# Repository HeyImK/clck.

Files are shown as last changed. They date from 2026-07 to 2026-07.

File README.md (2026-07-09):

# clck.

A custom battery-powered alarm clock built for the [Hack Club BLARE](https://blare.hackclub.com/) program.

The goal of this project was simple: build an aesthetic alarm clock with a hint of brutalism style that doesn't use cheap rubber buttons. Instead, it uses four Cherry MX mechanical keyboard switches, a custom PCB, and a 3D printed enclosure. Everything is powered by a Wemos ESP32-C3 Mini, which handles the display, buttons,buzzer, etc. Btw Sponsored by Hack Club too!!!

## Overview

### Enclosure

| Front | Back |
|---|---|
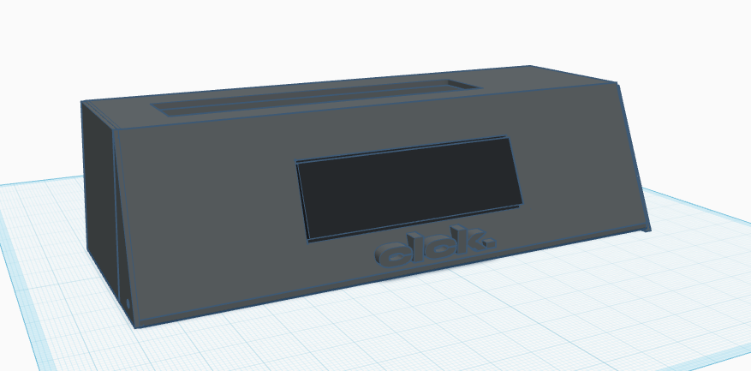
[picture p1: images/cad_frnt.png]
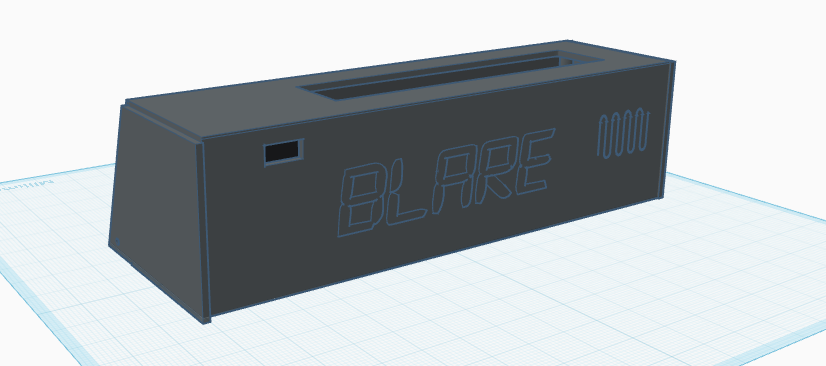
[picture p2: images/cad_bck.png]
|  |  |

### PCB

| Front | Back |
|---|---|
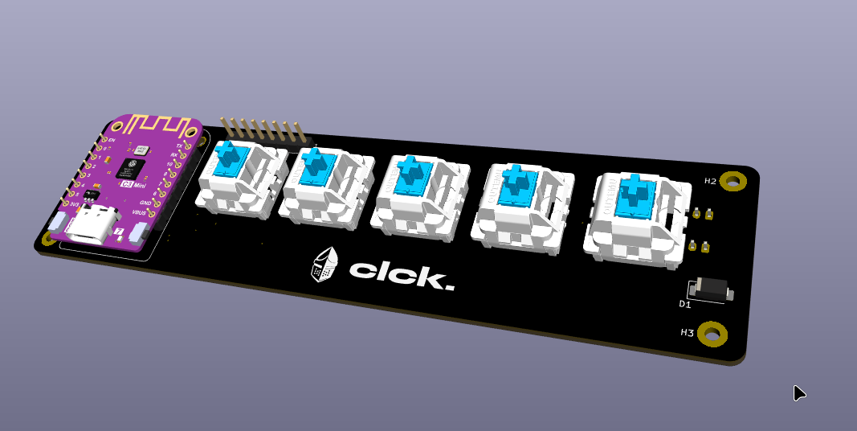
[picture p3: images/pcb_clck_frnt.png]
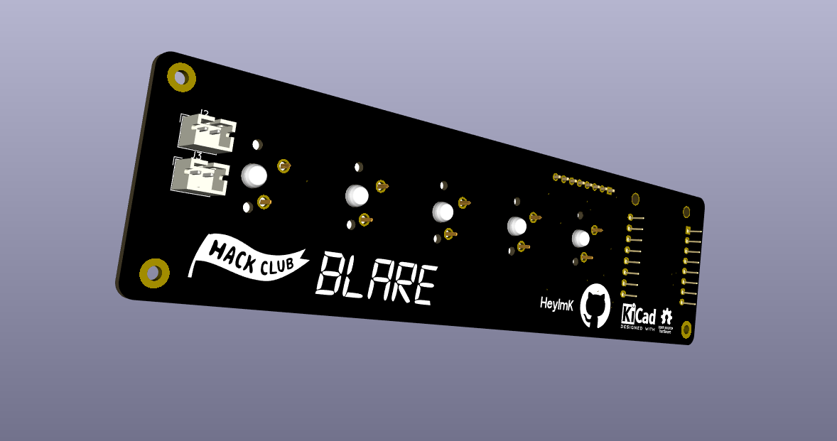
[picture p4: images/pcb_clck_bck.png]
|  |  |

### Electronics

| Schematic | PCB Routing |
|---|---|
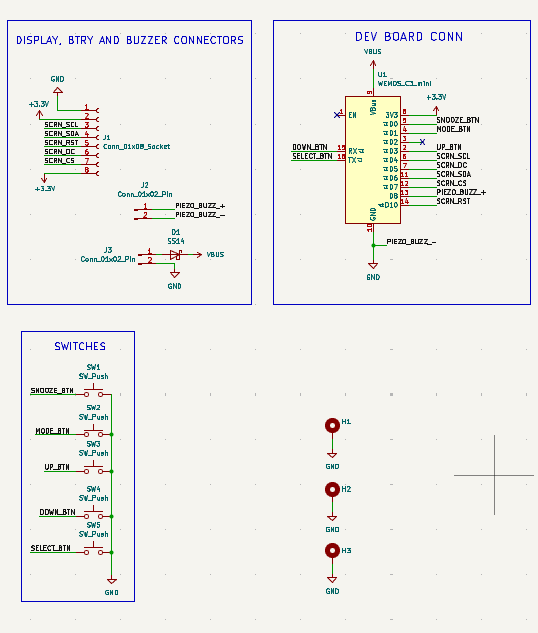
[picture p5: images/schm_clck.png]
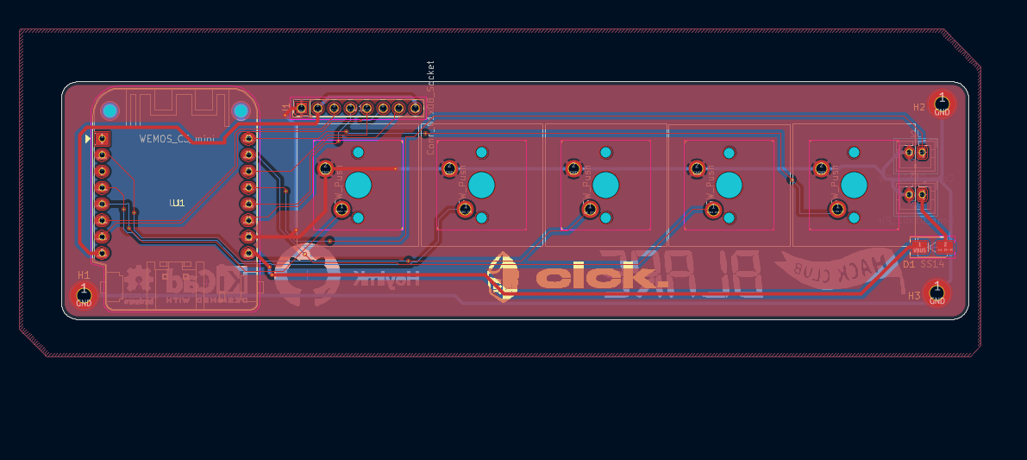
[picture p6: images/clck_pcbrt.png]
|  |  |

## Hardware

- Wemos ESP32-C3 Mini dev-board
- 2.25" SPI TFT display
- 4 Cherry MX mechanical switches
- Piezo buzzer
- Schottky diode (SS14)

The battery connects through a JST 2.0 connector and is charged using a external TP4056 module. 

## Pin Mapping

The ESP32-C3 Mini doesn't have many GPIOs, so every pin has been used by the display,buttons,buzzer etc.  

| Component | ESP32-C3 Pin(s) | Notes |
|---|---|---|
| Display (SPI) | GPIO4, GPIO6, GPIO7, GPIO2, GPIO10 | SCK, MOSI, CS, DC, RST |
| Piezo buzzer | GPIO8 | Connected to the positive terminal |
| Buttons | GPIO0, GPIO1, GPIO20, GPIO21 | Main control buttons |
| Battery input | VBUS |Connect to a charging module first |

## Assembly

The switch plate is designed around a thickness of **1.5 mm**. Making it thicker will prevent the Cherry MX switches from snapping into place correctly.

Before connecting the battery check the battery polarity.

## License

CERN-OHL-S-2.0 license

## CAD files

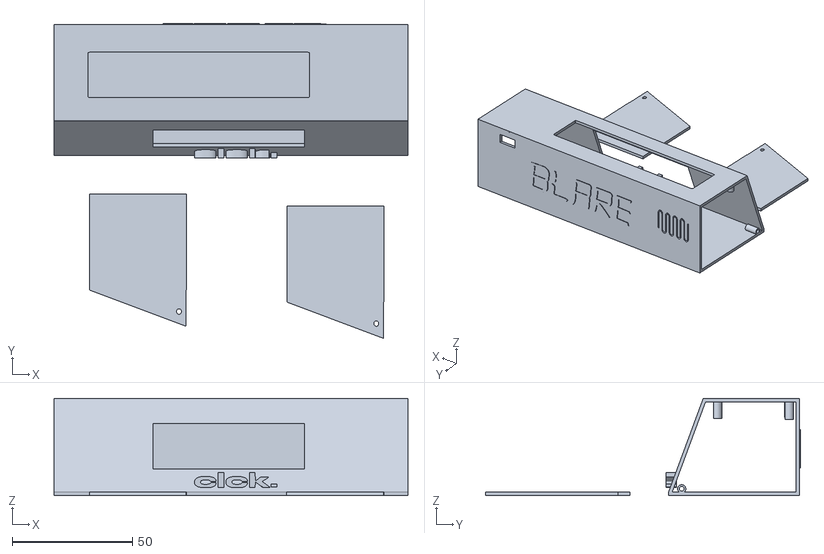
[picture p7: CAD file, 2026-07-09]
cad/clck. case.stl
147.1 x 130.8 x 40.5

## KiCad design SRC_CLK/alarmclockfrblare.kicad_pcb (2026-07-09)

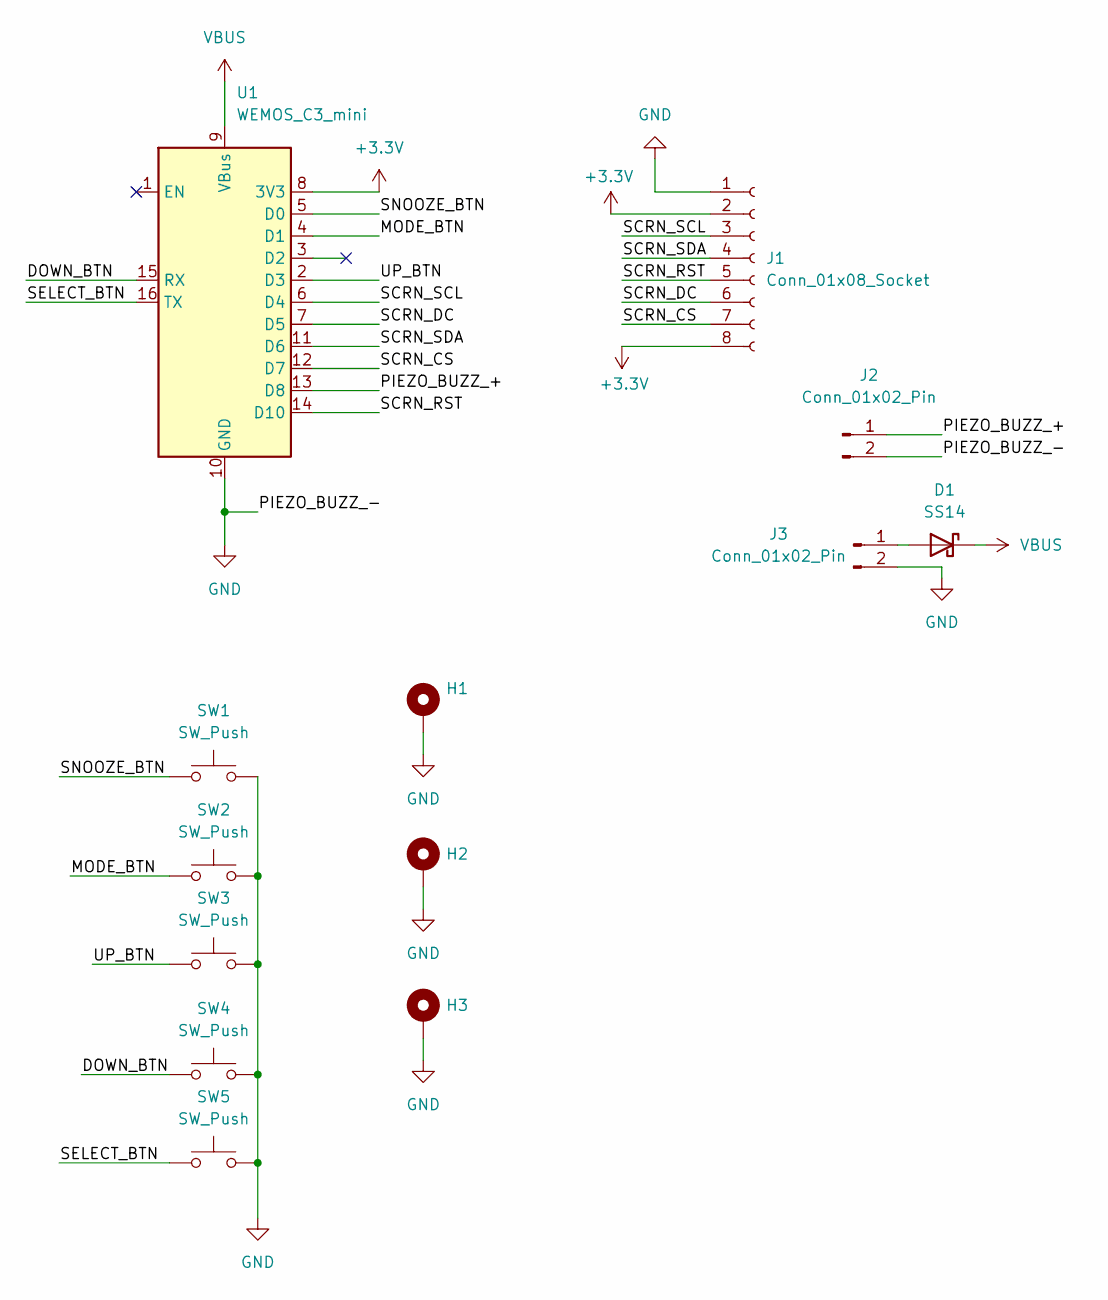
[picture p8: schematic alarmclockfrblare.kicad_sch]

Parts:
D1: SS14; D_SMA
H1, H2, H3: MountingHole_Pad; MountingHole_2.2mm_M2_Pad
J1: Conn_01x08_Socket; PinHeader_1x08_P2.54mm_Vertical
J2, J3: Conn_01x02_Pin; JST_PH_B2B-PH-K_1x02_P2.00mm_Vertical
SW1, SW2, SW3, SW4, SW5: SW_Push; SW_MX_1u
U1: WEMOS_C3_mini

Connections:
+3.3V: J1.2, J1.8, U1.8 (3V3)
/DOWN_BTN: SW4.1, U1.15 (RX)
/MODE_BTN: SW2.1, U1.4 (D1)
/PIEZO_BUZZ_+: J2.1, U1.13 (D8)
/SCRN_CS: J1.7, U1.12 (D7)
/SCRN_DC: J1.6, U1.7 (D5)
/SCRN_RST: J1.5, U1.14 (D10)
/SCRN_SCL: J1.3, U1.6 (D4)
/SCRN_SDA: J1.4, U1.11 (D6)
/SELECT_BTN: SW5.1, U1.16 (TX)
/SNOOZE_BTN: SW1.1, U1.5 (D0)
/UP_BTN: SW3.1, U1.2 (D3)
GND: H1.1 (1_1), H2.1 (1_1), H3.1 (1_1), J1.1, J2.2, J3.2, SW1.2, SW2.2, SW3.2, SW4.2, SW5.2, U1.10 (GND)
unnamed: D1.2 (A), J3.1
VBUS: D1.1 (K), U1.9 (VBus)

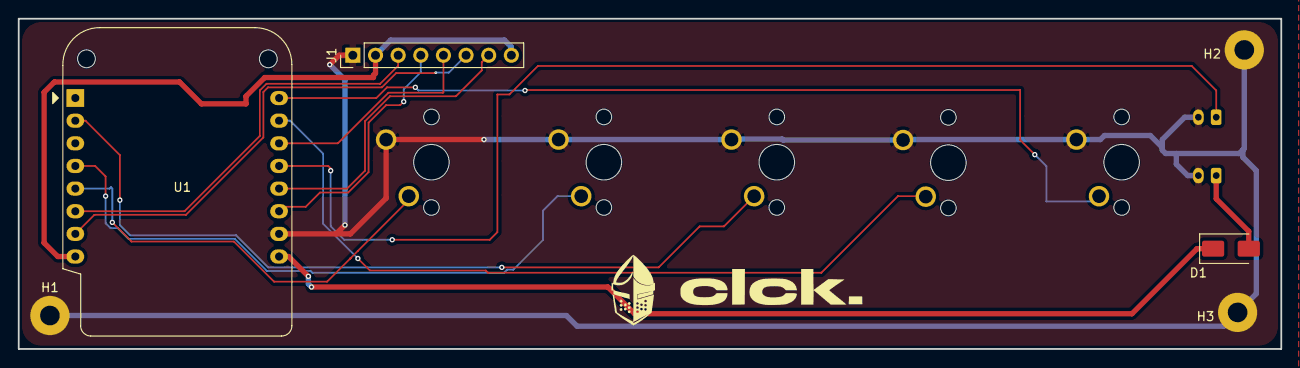
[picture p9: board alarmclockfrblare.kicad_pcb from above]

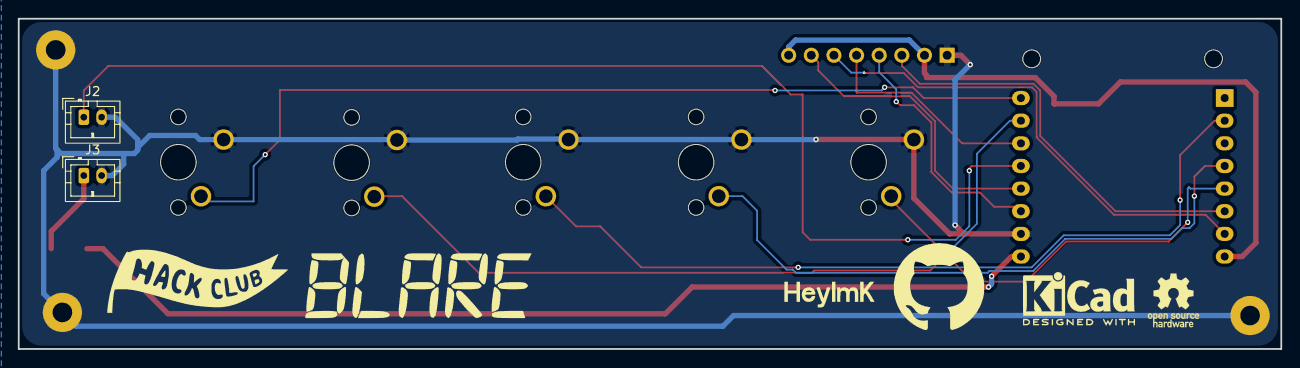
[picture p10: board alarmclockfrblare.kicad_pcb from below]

Board: 2 copper layers, 141.7 x 37.1 mm, 13 parts (2 on the bottom side), 15 nets.
